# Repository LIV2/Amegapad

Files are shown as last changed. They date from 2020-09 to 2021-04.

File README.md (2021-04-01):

# Amegapad - Megadrive 6-Button pad adapter for Amiga

This is an Adapter that allows the use of 6-button controllers on the Amiga and provides Autofire functionality

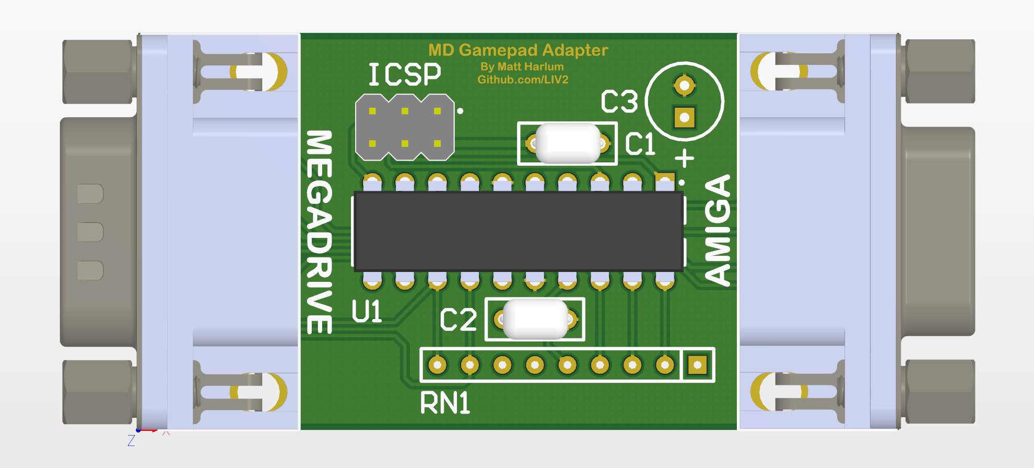
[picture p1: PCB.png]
PCB


### ~~Roadmap~~ Things I want to add but probably won't get around to

* Add ability to configure button mapping on the fly
* Add ability to change Autofire speed on the fly
* Try to add support for CD32 Controller protocol, this will require a new PCB revision

### Bill of materials
|Component|Location|QTY|Link|
|---|---|---|---|
|Attiny861a|U1|1|[Mouser](https://www.mouser.com/ProductDetail/556-ATTINY861A-PU)|
|DSUB9 Male right-angle|J1|1|[Mouser](https://www.mouser.com/ProductDetail/636-182-009-113R531)
|DSUB9 Female right-angle|J2|1|[Mouser](https://www.mouser.com/ProductDetail/182-009-213R561)|
|0.1uF Ceramic Capaictor|C1,C2|2|[Mouser](https://www.mouser.com/ProductDetail/594-K104K15X7RF53H5)|
|100uF Electrolytic Capacitor|C3|1|[Mouser](https://www.mouser.com/ProductDetail/667-ECA-1AM101I)|

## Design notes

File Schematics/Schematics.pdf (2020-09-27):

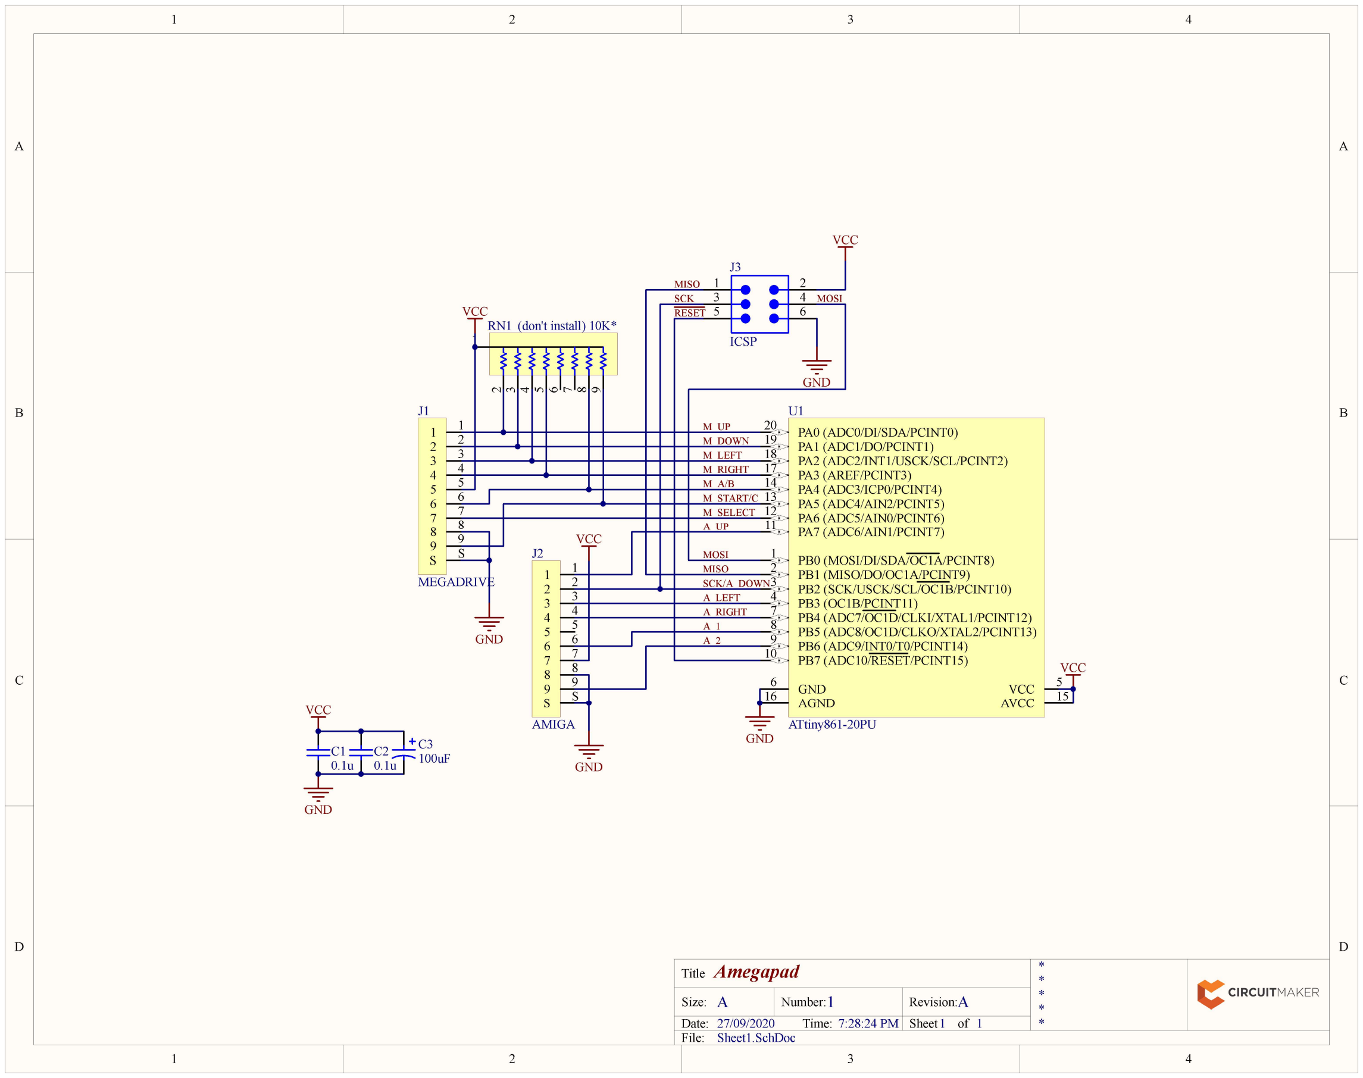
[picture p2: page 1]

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
## Amegapad

### 1 A

27/09/2020 | 7:28:24 PM
Sheet1.SchDoc

Title

Size: | Number:
Date:
File:

Revision:
Time: | Sheet | of

A

PB7 (ADC10/RESET/PCINT15) 10 PB6 (ADC9/INT0/T0/PCINT14) 9

PB3 (OC1B/PCINT11) 4

VCC 5

PB4 (ADC7/OC1D/CLKI/XTAL1/PCINT12) 7 PB5 (ADC8/OC1D/CLKO/XTAL2/PCINT13) 8

PB2 (SCK/USCK/SCL/OC1B/PCINT10) 3

PB1 (MISO/DO/OC1A/PCINT9) 2

PB0 (MOSI/DI/SDA/OC1A/PCINT8) 1

PA0 (ADC0/DI/SDA/PCINT0) 20 PA1 (ADC1/DO/PCINT1) 19

PA4 (ADC3/ICP0/PCINT4) 14

AVCC 15 AGND 16

PA2 (ADC2/INT1/USCK/SCL/PCINT2) 18

PA5 (ADC4/AIN2/PCINT5) 13
PA6 (ADC5/AIN0/PCINT6) 12
PA7 (ADC6/AIN1/PCINT7) 11

GND 6

PA3 (AREF/PCINT3) 17

U1

ATtiny861-20PU

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
AMIGA

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
RN1 | 10K*

M_UP
M_DOWN
M_LEFT
M_RIGHT
M_A/B
M_START/C
M_SELECT
A_UP

MOSI
MISO
SCK/A_DOWN
A_LEFT
A_RIGHT
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
ICSP

VCC

GND

MISO
SCK
RESET

MOSI

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
MEGADRIVE

C1
0.1u

C2
0.1u

GND

VCC

C3
100uF

(don't install)

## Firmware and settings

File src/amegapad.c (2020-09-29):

/*
Amegapad, a Megadrive gamepad for Amiga implemented on the Atmel ATTINY861A.
Copyright (C) 2020 Matt Harlum

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
You should have received a copy of the GNU General Public License
along with this program; if not, write to the Free Software
Foundation, Inc., 51 Franklin Street, Fifth Floor, Boston, MA  02110-1301, USA.
*/

#define F_CPU 8000000UL

#include <avr/io.h>
#include <avr/interrupt.h>
#include <util/delay.h>

#define M_UP     PA0
#define M_DOWN   PA1
#define M_LEFT   PA2
#define M_RIGHT  PA3
#define M_AB     PA4
#define M_STARTC PA5
#define M_SELECT PA6

#define A_UP     PA7
#define A_DOWN   PB2
#define A_LEFT   PB3
#define A_RIGHT  PB4
#define A_1      PB5
#define A_2      PB6

#define BTN_UP     (1<<0)
#define BTN_DOWN   (1<<1)
#define BTN_LEFT   (1<<2)
#define BTN_RIGHT  (1<<3)
#define BTN_B      (1<<4)
#define BTN_C      (1<<5)
#define BTN_A      (1<<6)
#define BTN_START  (1<<7)

#define BTN_Z      (1<<0)
#define BTN_Y      (1<<1)
#define BTN_X      (1<<2)
#define BTN_MODE   (1<<3)

/*
 Autofire configuration.
 If configuring one of X Y Z as an autofire button then the relevant state is buttonstate2
 Otherwise use buttonstate1
*/
#define AUTOFIRE_A_BUTTON BTN_Y
#define AUTOFIRE_A_STATE  buttonstate2
#define AUTOFIRE_B_BUTTON BTN_C
#define AUTOFIRE_B_STATE  buttonstate1

#define AF_FRAMES  3 // Autofire modulo - configures autofire rate

uint8_t buttonstate1;
uint8_t buttonstate2;
uint8_t counter;

void setup(void)
{
  cli();
  PORTA |= (1<<M_UP|1<<M_DOWN|1<<M_LEFT|1<<M_RIGHT|1<<M_AB|1<<M_STARTC); // Pull-up enabled

  PORTA |= (1<<A_UP);
  PORTB |= (1<<A_LEFT|1<<A_RIGHT|1<<A_DOWN|1<<A_1|1<<A_2);

  DDRA |= (1<<M_SELECT);

  OCR0A = 78; // 100HZ twice a PAL frame
  TCNT0H = 0;
  TCNT0L = 1;
  TCCR0A |= (1<<WGM00);  // CTC mode
  TCCR0B |= (1<<CS02|1<<CS00); // /1024 prescaler
 
  TIMSK |= (1<<OCIE0A);
  sei();
}
 
void setButton(uint8_t button, uint8_t pin) {
  if (buttonstate1 & button) {
    DDRB &= ~(1<<pin);  // Input
    PORTB |= (1<<pin);  // High - Pull-up enable
  } else {
    PORTB &= ~(1<<pin); // Low
    DDRB |= (1<<pin);   // Output
  }
}

void setFire(uint8_t pin, uint8_t state) {
  if (state) {
    PORTB &= ~(1<<pin); // Low
    DDRB |= (1<<pin);   // Output
  } else {
    DDRB &= ~(1<<pin);  // Input
    PORTB |= (1<<pin);  // High - Pull-up enable
  }
}

void setSelect(uint8_t state) {
  if (state % 2) {
    PORTA |= (1<<M_SELECT);
  } else {
    PORTA &= ~(1<<M_SELECT);
  }
}

ISR (TIMER0_COMPA_vect) {
  counter++;
  for (uint8_t state=0;state<=7;state++) {
    setSelect(state);
    switch(state)
    {
      case 0:
      case 1:
        buttonstate1 = 0;
        break;
      case 2:
        // Buttons: A, Start
        buttonstate1 |= ((PINA & 0x30) << 2);
        break;
      case 3:
        // Buttons: Up,Down,Left,Right,B,C
        buttonstate1 |= (PINA & 0x3F);
        break;
      case 4:
        if (((PINA & 0x03) == 0x03)) {
          // Not a 6-button controller, skip the rest
          state = 6;
          buttonstate2 = 0xFF;
        }
        break;
      case 5:
        buttonstate2 = (PINA & 0x0F);
        break;
      case 6:
        break;
      case 7:
        if (buttonstate1 & BTN_UP) {
          DDRA &= ~(1<<A_UP);  // Input
          PORTA |= (1<<A_UP);  // High - Pull-up enable
        } else {
          PORTA &= ~(1<<A_UP); // Low
          DDRA |= (1<<A_UP);   // Output
        }
        setButton(BTN_DOWN,A_DOWN);
        setButton(BTN_LEFT,A_LEFT);
        setButton(BTN_RIGHT,A_RIGHT);
        if (!(AUTOFIRE_A_STATE & AUTOFIRE_A_BUTTON)) {
          setFire(A_1, counter % AF_FRAMES);
        } else {
          setButton(BTN_A,A_1);
        }
        if (!(AUTOFIRE_B_STATE & AUTOFIRE_B_BUTTON)) {
          setFire(A_2, counter % AF_FRAMES);
        } else {
          setButton(BTN_B,A_2);
        }
        break;
      default:
        break;
    }
  }
  _delay_us(10);
}
 
int main(void)
{
  setup();
  while (1)
  {
  }
}

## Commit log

2020-09-27 Initial commit.
    [Sheet1.SchDoc]
2020-09-27 Add readme, gerbers
    [PCB1.GBL, PCB1.GBO, PCB1.GBS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]
2020-09-27 Add defines for autofire buttons

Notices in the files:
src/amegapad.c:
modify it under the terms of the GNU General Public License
